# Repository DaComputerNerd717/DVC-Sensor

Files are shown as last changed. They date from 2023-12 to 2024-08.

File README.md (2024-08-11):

# DVC-Sensor
UMD 2023 senior design deer detection project\
Arduino nano source code: deerdetionsensorarray.ino

This project was inspired by the large amount of damage caused by deer-vehicle collisions in Michigan. Our state has a large amount of deer, and any car that runs into a deer has a good chance to be totalled. This project aims to reduce deer collisions by providing detection modules and lights to notify drivers about deer approaching the road. 

So far, we have detection modules based on image processing, which do successfully detect deer. Two variations exist; one variation uses a Raspberry Pi for the image processing, and one uses an Arduino Nano instead. Some software has also been created to control the module, as well. 

A light module has also been created, in order to simplify the process of blinking a light and driving LEDs. The module is also designed with expansion in mind, with documentation including a possible way to use a diode and relay to drive more powerful or higher voltage lights. The schematics for the lighting module have been provided in the form of images in documentation, and KiCad project files. 

The project still needs more work to be done. One major point is improving the accuracy of the detector modules. The Pi version is overall more accurate, but neither are quite good enough. Furthermore, we have not tested either of these modules at scale, having only built one of each.

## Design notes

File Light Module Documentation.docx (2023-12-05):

Light Module Documentation

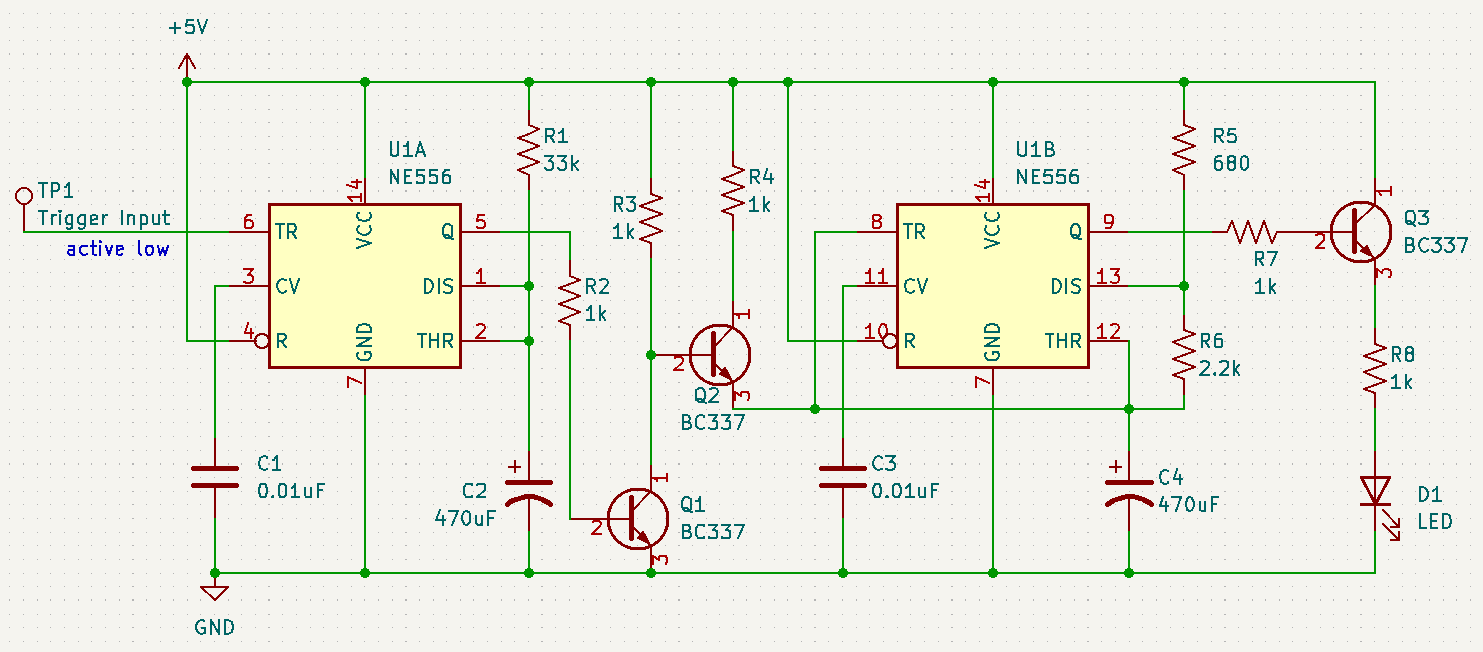
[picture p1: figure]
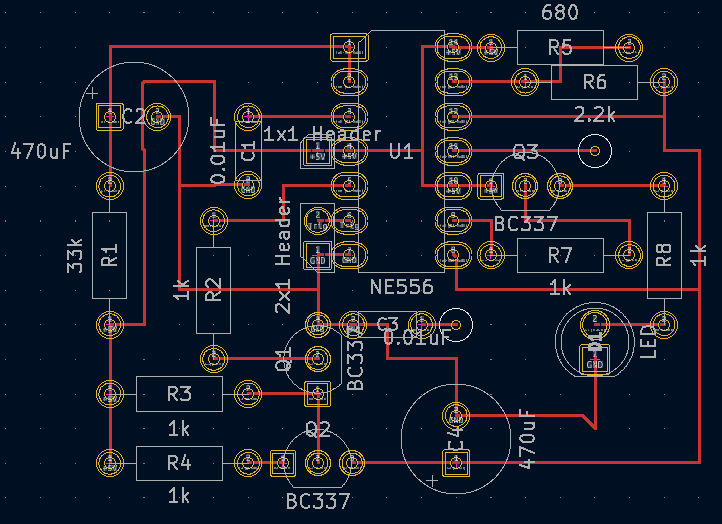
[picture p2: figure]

This module is built to make integration of a blinking light system into other systems easier. The circuit reduces the wiring to a basic power connection and a single trigger input. When the trigger input is given a low pulse (a change from a held high voltage to a temporary low voltage), a monostable (countdown-style) timer configuration set up by dual timer module U1, as well as R1 and C2, will count the duration for which the light should blink. Through Q1 and Q2, this then controls the astable (repeatedly running) timer assembled from U1, R5, R6, and C4. While the monostable timer counts down, the astable timer uses Q3 to blink light D1. If a second low-voltage pulse arrives, the monostable timer’s countdown resets without affecting the astable timer’s oscillations. 17 seconds after the last pulse, if another has not arrived, the monostable timer resets and the light stops blinking. Below is a rough, not-to-scale diagram which summarizes the behavior:

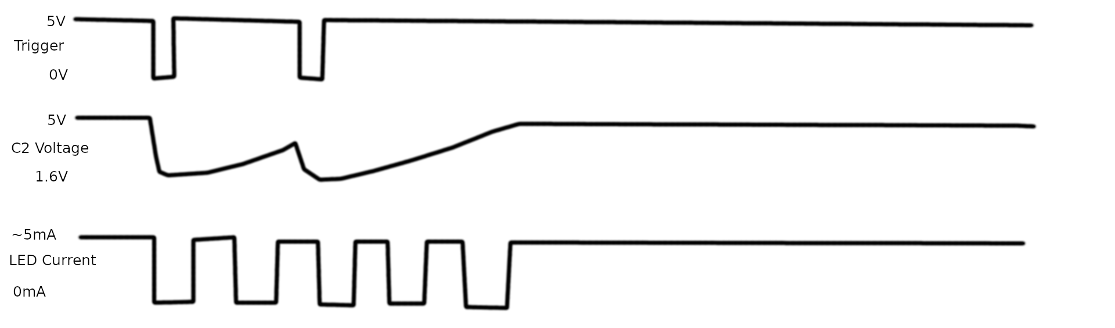
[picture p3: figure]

There are three headers in the circuit, a 1x1 header and a 2x1 header, just to the left of the IC, U1. These are the inputs required to integrate into the circuit. The single header should be a 5V power supply, such as a 5V pin on the Raspberry Pi. While 3.3V may work, it has not been tested and may make the light very dim.

In the 2x1 header, the slot furthest from the 1x1 header for power, labeled GND in the circuit board design, is the ground connection. This should be tied to the ground connection of the same device connected to the power supply input, such as the GND pins on a Raspberry Pi. Not connecting both power and ground to the same device may damage the light module and/or the connected devices. However, if the two devices have their ground connections tied together, that will be safe so long as this connection is maintained. For instance, since a Raspberry Pi HAT is generally connected to the Pi’s power and ground connections, the HAT’s ground circuit is equivalent to the Pi’s and will also be a safe place to connect this point. The ground header should have a connection to the ground circuit on the device supplying the power header.

The point on the 2x1 header closer to the 1x1 header, labeled “Trig” in the circuit board design, is the trigger input. This input should be held high to keep the light system idling. When the trigger input reaches a low voltage (defined as below 1/3 of the power supply voltage), the light will begin blinking. Once the trigger input returns to high, the light will continue pulsing for approximately 17 seconds. Essentially, to start the light blinking, send a single pulse. If the pulse is too short, the capacitor will be unable to fully discharge and may cause unexpected blinking times. A pulse of 1ms should be sufficient. If the light stops blinking after an unexpectedly short time (see the below formulas for the intended time; default 17 seconds), try a longer pulse.

Replacing the capacitor at C2 with another capacitor will rescale this blinking time. The specific formula for the time the blinking will continue for, in seconds, is 1.1×R1(in ohms (Ω))×C2 (in farads (F)) . Replacing R1 with a smaller resistor to change this time may cause large current draws on activation and is not recommended. Change C2 instead. The default value is approximately 1.1×(33×10^3 Ω)×(470×10^(-6) F)=17.061s . Ensure that any replacement capacitor is rated for more than the supply voltage and is placed in the same orientation; large capacitors are generally polarized and must be placed in the correct direction. Also note that to change the capacitor will require soldering. Soldering improperly may result in incorrect connections being made, which may damage this module and any connected devices. If you do not know how to solder, it is not recommended to attempt to change out the capacitor or any other part. It is also not recommended to change out other parts, as some are present to limit current to components which will be damaged by high current, and others have more complicated effects.

If the light must be replaced with a device requiring a higher voltage or current than the existing circuit can provide (limited to approximately 4.7V and 8mA), then the LED can be replaced with a relay and a diode, as shown in the circuit section below. The high power light controller should then be connected to this relay’s unconnected pins. However, this change is relatively complex, and has not been tested. Consult the datasheets for the high-power light system you are utilizing to see how best to control it and what relay is required. The power providing device should also be able to handle the current that the relay requires. As previously stated, if you do not know how to solder, it is not recommended to change out parts in the circuit.

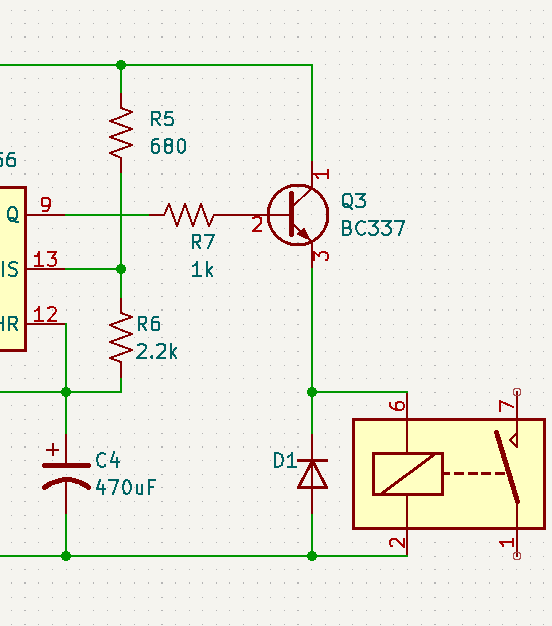
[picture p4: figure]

For initial setup, note that the device may blink when the system is initially set up, or blink for the wrong amount of time on the first run, regardless of the input. This is expected, as the capacitors may not be charged when the circuit is first powered on, and therefore the countdown may be in the middle of running. Similarly, if power to the module is cut and restored, and the timer was running when the power was cut, it may continue to blink after restoration, even though the intended time has passed, as the capacitor may not have discharged before power went out. Therefore, the module should generally be used for situations where power is consistent, and/or where a false positive reading is not as severe a problem as a false negative.

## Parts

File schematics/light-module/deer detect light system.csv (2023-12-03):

Source: | C:\Users\great\Documents\pi pedal 3254\deer detect light system\deer detect light system.kicad_sch
Date: | 12/2/2023 7:27:40 PM
Tool: | Eeschema (6.0.7)
Generator: | C:\Program Files\KiCad\6.0\bin\scripting\plugins/bom_csv_grouped_by_value.py
Component Count: | 18
Individual Components:
Item | Qty | Reference(s) | Value | LibPart | Footprint | Datasheet
 |  | C1 | 0.01uF | Device:C |  | ~
 |  | C2 | 470uF | Device:C_Polarized_US |  | ~
 |  | C3 | 0.01uF | Device:C |  | ~
 |  | C4 | 470uF | Device:C_Polarized_US |  | ~
 |  | D1 | LED | Device:LED | LED_THT:LED_D5.0mm_IRBlack | ~
 |  | Q1 | BC337 | Transistor_BJT:BC337 | Package_TO_SOT_THT:TO-92_Inline | https://diotec.com/tl_files/diotec/files/pdf/datasheets/bc337.pdf
 |  | Q2 | BC337 | Transistor_BJT:BC337 | Package_TO_SOT_THT:TO-92_Inline | https://diotec.com/tl_files/diotec/files/pdf/datasheets/bc337.pdf
 |  | Q3 | BC337 | Transistor_BJT:BC337 | Package_TO_SOT_THT:TO-92_Inline | https://diotec.com/tl_files/diotec/files/pdf/datasheets/bc337.pdf
 |  | R1 | 33k | Device:R_US |  | ~
 |  | R2 | 1k | Device:R_US |  | ~
 |  | R3 | 1k | Device:R_US |  | ~
 |  | R4 | 1k | Device:R_US |  | ~
 |  | R5 | 680 | Device:R_US |  | ~
 |  | R6 | 2.2k | Device:R_US |  | ~
 |  | R7 | 1k | Device:R_US |  | ~
 |  | R8 | 1k | Device:R_US |  | ~
 |  | TP1 | Trigger Input | Connector:TestPoint |  | ~
 |  | U1 | NE556 | Timer:NE556 |  | http://www.ti.com/lit/ds/symlink/ne556.pdf
Collated Components:
Item | Qty | Reference(s) | Value | LibPart | Footprint | Datasheet
1 | 2 | C1, C3 | 0.01uF | Device:C |  | ~
2 | 2 | C2, C4 | 470uF | Device:C_Polarized_US |  | ~
3 | 1 | D1 | LED | Device:LED | LED_THT:LED_D5.0mm_IRBlack | ~
4 | 3 | Q1, Q2, Q3 | BC337 | Transistor_BJT:BC337 | Package_TO_SOT_THT:TO-92_Inline | https://diotec.com/tl_files/diotec/files/pdf/datasheets/bc337.pdf
5 | 1 | R1 | 33k | Device:R_US |  | ~
6 | 5 | R2, R3, R4, R7, R8 | 1k | Device:R_US |  | ~
7 | 1 | R5 | 680 | Device:R_US |  | ~
8 | 1 | R6 | 2.2k | Device:R_US |  | ~
9 | 1 | TP1 | Trigger Input | Connector:TestPoint |  | ~
10 | 1 | U1 | NE556 | Timer:NE556 |  | http://www.ti.com/lit/ds/symlink/ne556.pdf

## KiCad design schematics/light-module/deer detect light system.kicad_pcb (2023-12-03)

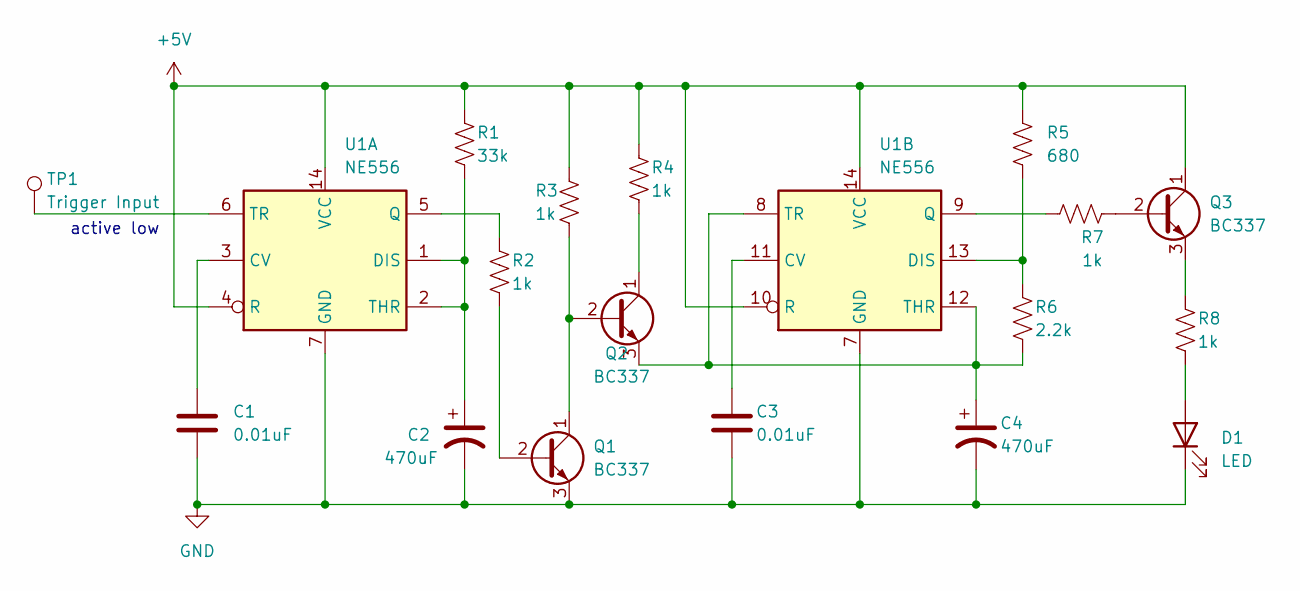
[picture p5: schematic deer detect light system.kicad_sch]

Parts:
C1, C3: 0.01uF
C2, C4: 470uF
D1: LED; LED_D5.0mm_IRBlack
Q1, Q2, Q3: BC337; TO-92_Inline
R1: 33k
R2, R3, R4, R7, R8: 1k
R5: 680
R6: 2.2k
TP1: Trigger Input
U1: NE556

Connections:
+5V: Q3.1 (C), R1.1, R3.1, R4.1, R5.1, U1.4 (R), U1.10 (R), U1.14 (VCC)
GND: C1.2, C2.2, C3.2, C4.2, D1.1 (K), Q1.3 (E), U1.7 (GND)
unnamed: C1.1, U1.3 (CV)
unnamed: C2.1, R1.2, U1.1 (DIS), U1.2 (THR)
unnamed: C3.1, U1.11 (CV)
unnamed: C4.1, Q2.3 (E), R6.2, U1.8 (TR), U1.12 (THR)
unnamed: D1.2 (A), R8.2
unnamed: Q1.1 (C), Q2.2 (B), R3.2
unnamed: Q1.2 (B), R2.2
unnamed: Q2.1 (C), R4.2
unnamed: Q3.2 (B), R7.2
unnamed: Q3.3 (E), R8.1
unnamed: R2.1, U1.5 (Q)
unnamed: R5.2, R6.1, U1.13 (DIS)
unnamed: R7.1, U1.9 (Q)
unnamed: TP1.1, U1.6 (TR)

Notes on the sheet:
active low

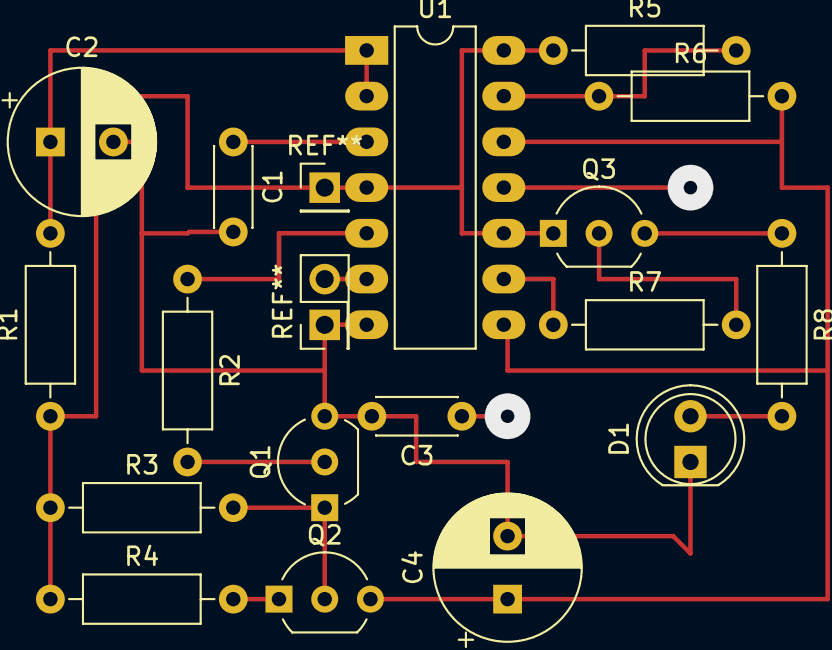
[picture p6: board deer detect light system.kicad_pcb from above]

Board: 2 copper layers, 17 parts (0 on the bottom side), 15 nets.

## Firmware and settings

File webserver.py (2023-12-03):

##############################################################################
#                                                        #
#   Deer Detection                                        #
#   Version: Prototpe                                                          #
##############################################################################

# -*- coding: utf-8 -*-
from flask import Flask,render_template,Response,request,redirect,jsonify,url_for
from flask_cors import CORS, cross_origin
import os
import io
import logging
import socketserver
from http import server
from threading import Condition
from picamera2 import Picamera2
from picamera2.encoders import JpegEncoder
from picamera2.outputs import FileOutput
from werkzeug.utils import secure_filename
import time
from datetime import *
import time
import math
import subprocess
import numpy as np
from werkzeug.security import generate_password_hash, check_password_hash
import subprocess
from pycurl import Curl
from urllib.parse import urlencode
import socket
import requests
from ftplib import FTP
from zipfile import ZipFile
import sqlite3 as lite
import cv2
import socket
import RPi.GPIO as GPIO
GPIO.setmode(GPIO.BCM)
LED_PIN = 17
VUSB_PIN = 17
CHG_PIN = 18
LO_DT_PIN = 27
GPIO.setup(VUSB_PIN, GPIO.IN)
GPIO.setup(CHG_PIN, GPIO.IN)
GPIO.setup(LO_DT_PIN, GPIO.IN)
GPIO.setup(LED_PIN, GPIO.OUT)
GPIO.output(LED_PIN,GPIO.LOW)

app = Flask(__name__)

CORS(app, supports_credentials=True)
#PathToDatabase = "/home/system/PythonProjects/DeerDetector/static/main.db"
PathToDatabase = "/home/system/DeerDetector/static/main.db"

CurrentPage = 1
PerPage = 25
pages = 0
LastPage = 1
loggedin = 0
message = ""
BatStatus = True

def BatState():
    global BatStatus
    charging = GPIO.input(CHG_PIN)
    low_battery = GPIO.input(LO_DT_PIN)
    external_power = GPIO.input(VUSB_PIN)
    # If it's not charging and the battery is low, shut down the pi
    # Even if the external power is connected, no charging means the power supply is not strong enough
    if not charging and low_battery:
        # Do some stuff before shutting down
        BatStatus = False
        # Shutdown
        print("Shutting down...")
        time.sleep(1)
        os.system("sudo shutdown -h now")

def save_config(data):
    global message
    try:
        con = lite.connect(PathToDatabase)
        cur = con.cursor()  
        cur.execute("UPDATE config SET device_id=?, itemsperpage = ?, pin = ?, save_images = ?, motion_duration = ? WHERE id=?",(data[0],data[1],data[2],data[3],data[4],1))
        con.commit()
        con.close()
        return True
    except lite.Error as error:
        print("SaveConfig: Error: ",error)
        return False
    except Exception as e:
        print("SaveConfig: Exception: ",e)
        return False

def update_version(data):
    global message
    try:
        con = lite.connect(PathToDatabase)
        cur = con.cursor()  
        cur.execute("UPDATE config SET version = ? WHERE id=?",(data,1))
        con.commit()
        con.close()
        return True
    except lite.Error as error:
        print("update_version: Error: ",error)
        return False
    except Exception as e:
        print("update_version: Exception: ",e)
        return False
           
def get_data(TableName, orderby="id",order="ASC",start=0,stop=0):
    con = lite.connect(PathToDatabase)
    con.row_factory = lite.Row
    try:
        cur = con.cursor()
        query = "SELECT * FROM %s" % TableName + " ORDER BY "+orderby+" "+order
        if stop > 0:
            query = "SELECT * FROM %s" % TableName + " ORDER BY "+orderby+" "+order+" LIMIT "+str(start)+","+str(stop)
        print(query)
        cur.execute(query)
        lines = cur.fetchall()
        print(lines)
        con.commit()
        if con:
            con.close()
            if len(lines) > 0:
                return lines
            else:
                return False 
    except Exception as e:
        if con:
            con.rollback()
            print("Error %s:" % e.args[0])
            return False

            
config = get_data("config")
appversion = config[0]['version']
NextVersion = appversion

def convert(seconds): 
    return time.strftime("%H:%M:%S", time.gmtime(seconds)) 

    
def get_ip_address():
    try:
        ip_address = ''
        s = socket.socket(socket.AF_INET, socket.SOCK_DGRAM)
        s.connect(("8.8.8.8",80))
        ip_address = s.getsockname()[0]
        s.close()
        return ip_address
    except Exception as e:
        print(e)
        return False
    
def save_LastIp(ip):
    try:
        con = lite.connect(PathToDatabase)
        cur = con.cursor()  
        cur.execute("UPDATE config SET lastip=? WHERE id=?",(ip,1))
        con.commit()
        con.close() 
        return True
    except lite.Error as error:
        print("Error: ",error)
        #save_event("flow.py save_event: sql error: ",str(error))
        return error
    except Exception as e:
        print("Exception: ",e)
        #save_event("flow.py save_event: Exception: ",str(e))
        return str(e)

start=0
def CalculatePagination(p,query,path,perpage):
    global start
    global CurrentPage
    from models import model
    data = model.MainModel.Paginate(model.MainModel,perpage,query)
    total_records = data[1]
    prev_page = p -1
    next_page = p + 1
    page = p
    pages = total_records / perpage # this is the number of pages
    pages = math.ceil(pages)
    offset = (page-1)*perpage # offset for SQL query
    limit = perpage
    if page == pages:
        limit = total_records
        next_page = pages
    else: 
        perpage # limit for SQL query
    if page < 2:
        prev_page=1
    #print("**********************",page,pages,offset,limit,"**********************")
    prev_path = path+str(prev_page)
    next_path = path+str(next_page)
    PageData =[prev_path,next_path,offset,limit,pages]
    #print(PageData)
    return PageData

def GetRowcount(data):
    x = 0
    for item in data:
        #print(item['step'])
        x+=1
    return x

def WriteData(data):
    try:
        stat = open("/home/system/DeerDetector/stat.txt","w")
        stat.write(data)
        return True
    except Exception as E:
        print("Failure ",E)
        return False
WriteData("off")

def GetData(): #Monitor video status, did we detect something?
    try:
        stat = open("/home/system/DeerDetector/vidstat.txt","r")
        data = stat.read()
        return data
    except Exception as E:
        print("Failure !!!!!!!!!!!!!!!!!!!!!!! ",E)
        return False

detection_status = "off"
sign_status = "off"
sensor1Status = "no"
sensor2Status = "no"
@app.errorhandler(404) 
def invalid_route(e):
	return render_template('404.html',error=e)

@app.route('/login', methods=["POST"])
def Auth():
    global loggedin
    global message
    config = get_data("config")
    pin = request.form['pin']
    if pin == config[0]['pin']:
        loggedin = 1
        message = "Logged In"
    else:
        loggedin = 0
        message = "Login Failed, please try again"
    return redirect('/config')

@app.route('/logout', methods=["GET"])
def logout():
    global loggedin
    global message
    loggedin = 0
    message = "Logged Out"
    return redirect('/')

@app.route('/', methods=["GET"])
def index():
    return render_template('index.html')


@app.route('/ClearLog/<string:table>', methods=["GET"])
def clearlog(table):
    from models import model
    if(table == "logs_motion"):
        model.MainModel.Clear_logs_motion(model.MainModel)
        return redirect('/logsMotion/1')
    if(table == "logs_detection"):
        model.MainModel.Clear_logs_detection(model.MainModel)
        return redirect('/logsDetection/1')

@app.route('/sensor1/<string:status>', methods=["GET"])
def sensor1(status):
    global detection_status
    global sensor1Status
    import json
    from models import model
    config = get_data("config")
    duration = int(config[0]['motion_duration'])*60
    print('motion_duration: ',duration)
    if status == "YES":
        model.MainModel.Insert_log_motion(model.MainModel,1)
        sensor1Status = "yes"
        print("Motion detected from Sensor: 1")
        print("Trigger camera for detection: ",config[0]['motion_duration']," Minutes")
        detection_status = "on"
        WriteData("on")
        time.sleep(duration)
        WriteData("off")
        sensor1Status = "no"
        detection_status = "off"

    res = '''{"status":"Recieved"}'''
    return json.loads(res)

@app.route('/sensor2/<string:status>', methods=["GET"])
def sensor2(status):
    global detection_status
    global sensor2Status
    import json
    from models import model
    config = get_data("config")
    duration = int(config[0]['motion_duration'])*60
    print('motion_duration: ',duration)
    if status == "YES":
        model.MainModel.Insert_log_motion(model.MainModel,2)
        sensor2Status = "yes"
        print("Motion detected from Sensor: 2")
        print("Trigger camera for detection: ",config[0]['motion_duration']," Minutes")
        detection_status = "on"
        WriteData("on")
        time.sleep(duration)
        WriteData("off")
        sensor2Status = "no"
        detection_status = "off"

    res = '''{"status":"Recieved"}'''
    return json.loads(res)

logged = False
@app.route('/sensor3', methods=["GET"])
def sensor3():
    global sign_status
    global logged
    config = get_data("config")
    from models import model
    import json
    data = GetData()
    print("Sensor3 ",data)
    try:
        BatState()
        if data != "":
            score = float(data)
        else:
            score = 0.0
        print("Sensor3 ",score)
        res = '''{"status":"off"}'''
        if score > 0.4:
            res = '''{"status":"on"}'''
            sign_status = "on"
            print("********************"," !!! Analyzing !!! ","************************")
            data = [score,"",config[0]['motion_duration']]
            if not logged:
                model.MainModel.Insert_log_detection(model.MainModel,data)
                logged = True
            return json.loads(res)
        else:
            logged = False
            res = '''{"status":"off"}'''
            return json.loads(res)
    except Exception as E:
        logged = False
        print("!!!!!!!!!!! ERROR !!!!!!!!!!",E)
        score = 0
        res = '''{"status":"off"}'''
        return json.loads(res)

@app.route('/sensor4/<string:status>', methods=["GET"])
def sensor4(status):
    global sign_status
    sign_status = status
    import json
    res = '''{"status":"ok"}'''
    return res

@app.route('/GetStatus', methods=["GET"])
def GetStatus():
    import json
    res = [str(sign_status),str(detection_status),str(sensor1Status),str(sensor2Status)]
    print(res)
    return res

@app.route('/config', methods=["GET"])
def config():
    global inventory
    global message
    titles = ['active','','','','']
    FileName = ""
    #update = CheckUpdate()
    if update:
        FileName = update
    BatStatus = True
    try:
        voltage = subprocess.check_output("dmesg | grep -iC 3 'Undervoltage'", shell=True)
        if "Undervoltage" in str(voltage):
            BatStatus = False
            GPIO.output(LED_PIN,GPIO.HIGH)
            print("LOW BATTERY")
        else:
            BatStatus = True
        if "normalised" in str(voltage):
            BatStatus = True
            print("GOOD BATTERY")
            GPIO.output(LED_PIN,GPIO.LOW)
    except:
        BatStatus = True

    config = get_data("config")       
    return render_template('config.html',title = titles,BatStatus=BatStatus,FileName=FileName,update=update,config=config,loggedin=loggedin,message=message) 
    
@app.route('/logsDetection/<int:page>', methods=["GET"])
def logsDetection(page):
    global message
    FileName = ""
    update = False
    titles = ['','active','','','']
    BatStatus = True
    from models import model
    pagination = CalculatePagination(page,"SELECT * FROM logs_detection ORDER BY id ASC","/recipes/",25)
    try:
        voltage = subprocess.check_output("dmesg | grep -iC 3 'Undervoltage'", shell=True)
        if "Undervoltage" in str(voltage):
            BatStatus = False
            print("LOW BATTERY")
        else:
            BatStatus = True
        if "normalised" in str(voltage):
            BatStatus = True
            print("GOOD BATTERY")
            #GPIO.output(LED_PIN,GPIO.LOW)
    except:
        BatStatus = True
    logs_detection = model.MainModel.Get_logs_detection(model.MainModel,pagination[2],pagination[3])
    config = get_data("config")       
    return render_template('detectionlogs.html',logs_detection=logs_detection,title=titles,BatStatus=BatStatus,FileName=FileName,update=update,config=config,loggedin=loggedin,message=message,prev=pagination[0],next=pagination[1],page=page)

@app.route('/logsMotion/<int:page>', methods=["GET"])
def logsMotion(page):
    global message
    FileName = ""
    update = False
    titles = ['','','active','','']
    BatStatus = True
    from models import model
    pagination = CalculatePagination(page,"SELECT * FROM logs_motion ORDER BY id ASC","/recipes/",25)
    try:
        voltage = subprocess.check_output("dmesg | grep -iC 3 'Undervoltage'", shell=True)
        if "Undervoltage" in str(voltage):
            BatStatus = False
            print("LOW BATTERY")
        else:
            BatStatus = True
        if "normalised" in str(voltage):
            BatStatus = True
            print("GOOD BATTERY")
            #GPIO.output(LED_PIN,GPIO.LOW)
    except:
        BatStatus = True
    logs_motion = model.MainModel.Get_logs_motion(model.MainModel,pagination[2],pagination[3])
    config = get_data("config")       
    return render_template('motionlogs.html',logs_motion=logs_motion,title=titles,BatStatus=BatStatus,FileName=FileName,update=update,config=config,loggedin=loggedin,message=message,prev=pagination[0],next=pagination[1],page=page)
    
@app.route('/files/<int:page>', methods=["GET"])
def files(page):
    global inventory
    global message
    FileName = ""
    titles = ['','','','active','']
    update = False
    from models import model
    pagination = CalculatePagination(page,"SELECT * FROM files ORDER BY date DESC","/files/",25)
    print(pagination)
    files = model.MainModel.Get_files(model.MainModel,pagination[2],pagination[3])
    
    BatStatus = True
    try:
        voltage = subprocess.check_output("dmesg | grep -iC 3 'Undervoltage'", shell=True)
        if "Undervoltage" in str(voltage):
            BatStatus = False
            print("LOW BATTERY")
        else:
            BatStatus = True
        if "normalised" in str(voltage):
            BatStatus = True
            print("GOOD BATTERY")
            #GPIO.output(LED_PIN,GPIO.LOW)
    except:
        BatStatus = True
    #print(update)
    config = get_data("config")       
    return render_template('files.html',files=files,title=titles,BatStatus=BatStatus,FileName=FileName,update=update,config=config,loggedin=loggedin,message=message,prev=pagination[0],next=pagination[1],page=page)

@app.route('/fileEdit/<int:id>', methods=["GET"])
def fileEdit(id):
    config = get_data("config")
    from models import model
    file = model.MainModel.GetFile(id)
    titles = ['','','','active','']
    return render_template('file.html',config=config,title=titles,FileName=file[0])

@app.route('/updatefile/<int:id>', methods=["GET","POST"])
def updatefile(id):
    from models import model
    print(request.form) 
    data = [
        request.form.get("comments"),
        id
    ]
    model.MainModel.Update_Image(model.MainModel,data)
    return redirect('/files')

@app.route('/DeleteFile/<int:id>/<string:filename>', methods=["GET","POST"])
def DeleteFile(id,filename):
    from models import model
    model.MainModel.Delete_Image(model.MainModel,id,filename)
    return redirect('/files/1')

@app.route('/uploadmodel', methods = ["POST","GET"])
def uploadmodel():
    if request.files:
        file = request.files['file']
        if file.filename != '':
            filename = secure_filename(file.filename)
            file.save(os.path.join("", filename))
    return redirect("/config")

@app.route('/uploadFW', methods = ["POST","GET"])
def uploadFW():
    if request.files:
        file = request.files['file']
        if file.filename != '':
            filename = secure_filename(file.filename)
            file.save(os.path.join("", filename))
    return redirect("/update/"+filename)

@app.route('/update/<string:FileName>', methods=["GET"])
def update(FileName):
    global message
    return render_template('update.html',FileName=FileName,config=config)
    


@app.route('/save_config', methods=["POST"])
def saveconfig():
    global message
    global currentSSID
    global curentPassphrase
    config = []
    config.append(request.form['device_id'])
    config.append(request.form['itemsperpage'])
    config.append(request.form['pin'])
    config.append(request.form['save_images'])
    config.append(request.form['motion_duration'])
    save_config(config)
    return redirect("/config")

@app.route('/preview', methods=["GET"])
def preview():
    titles = ['','','','','active']
    config = get_data("config")
    return render_template('video.html',title=titles,config=config)

@app.route('/confirmrestart', methods=["GET"])
def ConfRestart():
    config = get_data("config")
    ipaddress = get_ip_address()
    return render_template('restart.html',config=config,last_ip=ipaddress)

@app.route('/confirmstop', methods=["GET"])
def ConfStop():
    return render_template('stop.html')

@app.route('/restart', methods=["GET"])
def Restart():
    os.system("sudo reboot &")
    return "REBOOTING"

@app.route('/stop', methods=["GET"])
def Stop():
    os.system("sudo shutdown now &")
    return "Shutdown"

@app.route('/checkconnect', methods=["GET"])
def checkconnect():
    ipaddress = get_ip_address()
    return ipaddress
#Orient the screen 90 Deg. right

if __name__ == '__main__':
    app.run(host='10.42.0.1',port=5000, debug=False, threaded=True)

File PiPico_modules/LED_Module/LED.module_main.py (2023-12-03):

#LED Module, main.py
# Import modules
import network
import urequests
from machine import Pin, ADC
import time
import gc
led = machine.Pin("LED", machine.Pin.OUT)
strobe = Pin(1, Pin.OUT, Pin.PULL_DOWN)
led.off()
SensorID = 3
ServerAddress = "10.42.0.1"
# Connect to WLAN
wlan = network.WLAN(network.STA_IF)
wlan.active(True)
wlan.connect("deer", "SaveTheDeer")
time.sleep(3)
print(wlan.ifconfig())
BootTimer = 0
ErrorCount = 0
while True:
    print(wlan.ifconfig())
    print(BootTimer)
    if BootTimer >= 3600: #Reboot once an hour
        print("Hourly Reboot in progress")
        led.on()
        machine.reset()
    gc.collect()
    try:
        response = urequests.get('http://'+ServerAddress+':5000/sensor3')
        data = response.json()
        print(data['status'])
        if data['status'] == "on":
            led.on()
        if data['status'] == "off":
            led.off()
    except Exception as E:
        ErrorCount += 1
        print("Server not responding: \n",E,ErrorCount)
        if ErrorCount > 30:
            led.on()
            machine.reset()

        pass
    time.sleep(1)
    BootTimer += 1

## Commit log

2023-12-03 Add light module schematic files
    These files are meant to be opened with KiCad version 6. Any older version of KiCad may not work.
    [deer detect light system.csv, deer detect light system.kicad_pcb, deer detect light system.kicad_sch]
2024-08-11 Update README.md
    Added description of project, current achievements, and work to be done to README
